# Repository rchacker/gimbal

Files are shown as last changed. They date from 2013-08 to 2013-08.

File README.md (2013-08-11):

gimbal
=======

Gimbal forked from _BruGi

Aim is to have a very simple 8 bit gimbal for which basic parameters are adjustable in the field without needing a computer.

Agouti Prototype

Agouti Prototype  
*Agouti Prototype*

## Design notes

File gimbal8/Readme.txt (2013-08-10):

Arduino -> Tools -> Serial Monitor Settings
  Baudrate: 11200 Baud, NL and CR

######################################
List of serial commands:
######################################

these are the preferred commands, use them for new GUIs !!

SD    (Set Defaults)
WE    (Writes active config to eeprom)
RE    (Restores values from eeprom to active config)
GC    (Recalibrates the Gyro Offsets)
par <parName> <parValue>   (general parameter read/set command)
    example usage:
       par                     ... list all config parameters
       par gyroPitchKi         ... list gyroPitchKi
       par gyroPitchKi 12000   ... set gyroPitchKi to 12000

HE     (print this output)
HE par (print config paramter description)	   

######################################
Config Parameters (list with "he par")
######################################

vers
  firmware version
  
versEEPROM
  eeprom version

gyroPitchKp/gyroRollKp
  pid controller P-value
gyroPitchKi/gyroRollKi
  pid controller I-value
gyroPitchKd/gyroRollKd
  pid controller D-value
accTimeConstant
  time constant of ACC complementary filter.
  controls how fast the gimbal follows ACC.
  unit = 1 sec, e.g. 7 = 7 seconds
mpuLPF
  low pass filter of gyro (DLPFMode)
  legal values are 0...6, 0=fastest 6=slowest
  use slow values if high frequency oscillations occur (still experimental)

angleOffsetPitch/angleOffsetRoll
  offset of gimbal zero position
  unit = 0.01 deg, e.g. 500 = 5.00 deg

dirMotorPitch/dirMotorRoll
  motor direction
  1 = normal, -1 = reverse direction
motorNumberPitch/motorNumberRoll
  assign motor output for pitch and roll, legal values are 0 or 1
maxPWMmotorPitch/maxPWMmotorRoll
  motor power, legal range 0 to 255

minRCPitch/minRCRoll
  RC minimum set point angle, unit = 1 deg
maxRCPitch/maxRCRoll
  RC maximum set point angle, unit = 1 deg
rcGain
  RC gain in Relative mode, specifies speed of gimbal movement
rcLPF
  RC low pass filter in Absolute mode, specified speed of gimbal movement
  unit = 0.1 sec, e.g. 20 = 2.0 seconds

rcModePPM
  0 ... use two RC PWM inputs on A0 and A1
  1 ... use PPM sum input on A0

rcChannelPitch
   RC channel assignment for RC pitch, legal values are 0 to 7 in PPM mode
rcChannelRoll
   RC channel assignment for RC roll, legal values are 0 to 7 in PPM mode

rcMid
   RC center position, unit = 1 msec, default=1500
rcAbsolute
   0 ... RC Relative Mode, gimbal position is incremented/decremented by RC
   1 ... RC Absolute Mode, RC controls gimbal directly

accOutput
   1 ... enable ACC printout for GUI chart display
enableGyro/enableACC
   1 ... enable Gyro/ACC update in control loop
         just for test and adjustment purposes

axisReverseZ
   0 ... sensor is mounted with component side up
   1 ... sensor is mounted with component side down
axisSwapXY
   0 ... standard X/Y sensor orientation
   1 ... swap X/Y, exchange roll/pitch function, when sensor is rotated 90 degrees

crc
   EEPROM checksum

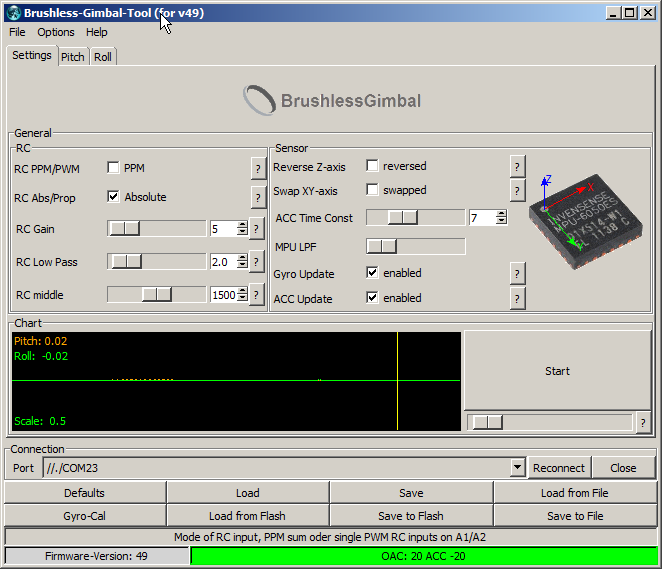
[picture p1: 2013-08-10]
GUI/Settings-GoPro-typical-Brugi_049_01.png

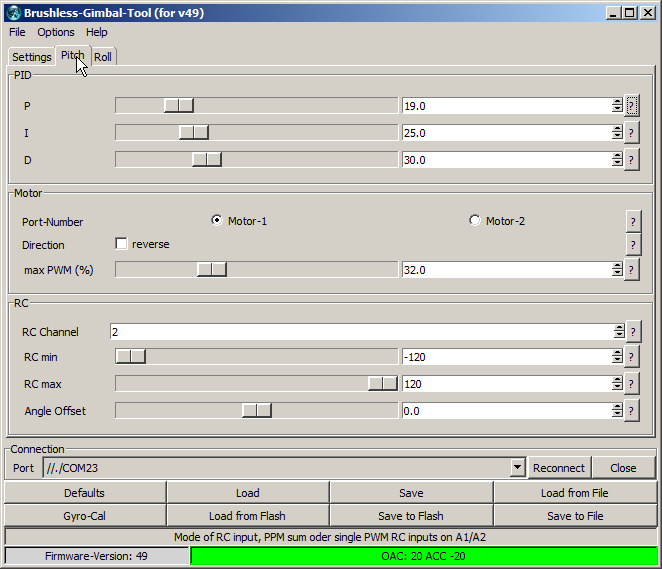
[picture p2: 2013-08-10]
GUI/Settings-GoPro-typical-Brugi_049_02.png

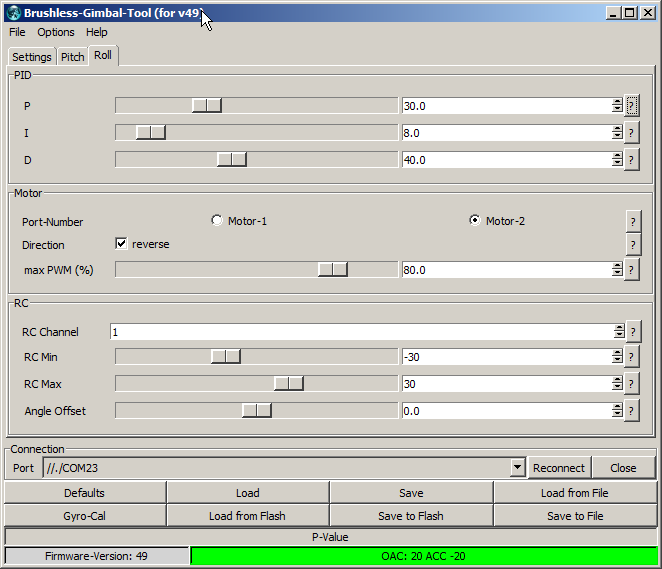
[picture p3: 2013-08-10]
GUI/Settings-GoPro-typical-Brugi_049_03.png

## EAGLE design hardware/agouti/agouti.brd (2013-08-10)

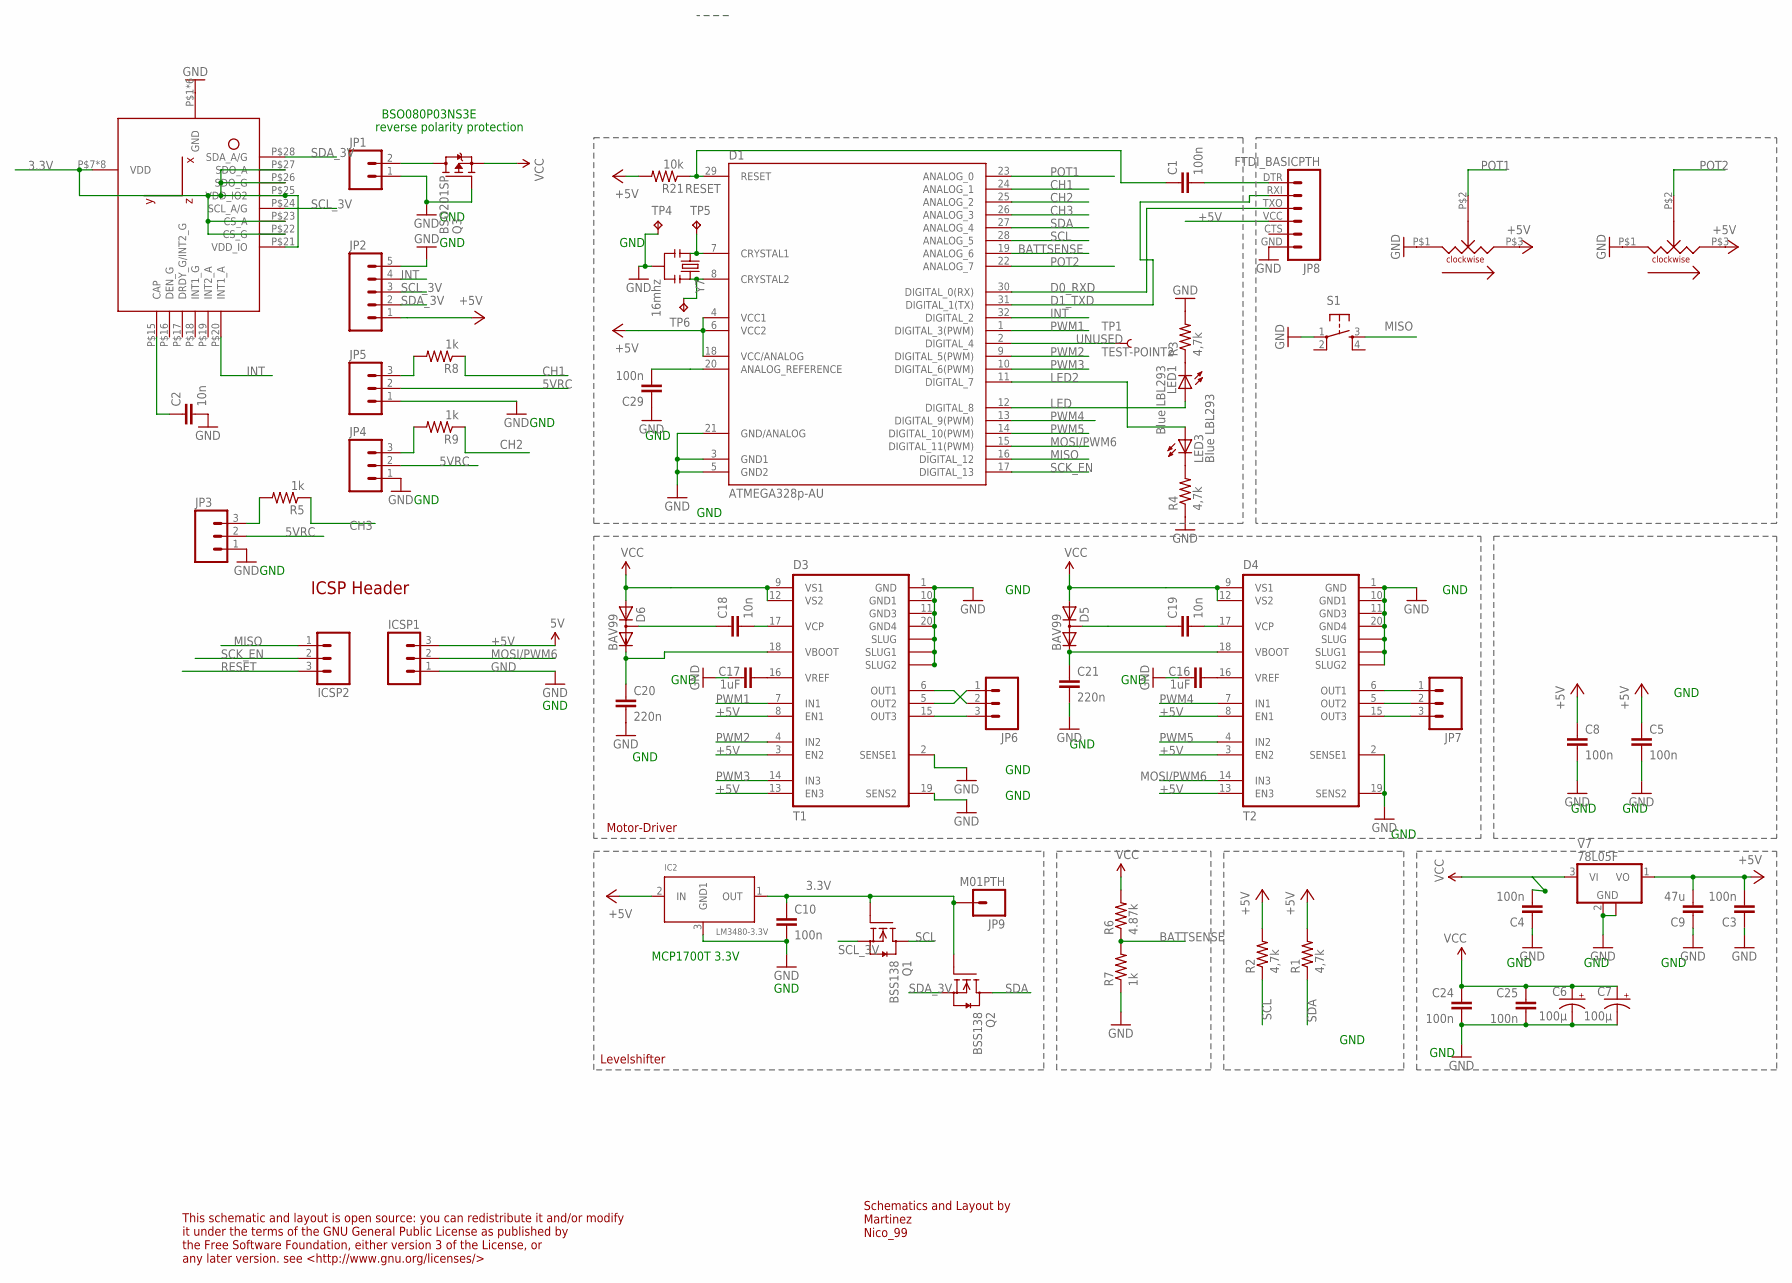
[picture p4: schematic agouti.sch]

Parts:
C1, C3, C4, C5, C8, C10, C24, C25, C29: 100n; 0805
C2, C18, C19: 10n; 0805
C6, C7: 100µ; PANASONIC_D
C9: 47u; C1210
C16, C17: 1uF; 0805
C20, C21: 220n; 0805
D1: ATMEGA328p-AU; TQFP32-08
D3: T1; SO20POWER2
D4: T2; SO20POWER2
D5, D6: BAV99; SOT23
IC2: LM3480-3.3V; SOT23
ICSP1, ICSP2: M03PTH; 1X03
JP1: M02PTH; 1X02
JP2: M05PTH; 1X05
JP3, JP4, JP5, JP6, JP7: M03PTH; 1X03
JP8: FTDI_BASICPTH; FTDI_BASIC
JP9: M01PTH; 1X01
LED1, LED3: Blue LBL293; CHIP-LED0603
Q1, Q2: BSS138; SOT23
Q3: BSO201SP; SO-8
R1, R2, R3, R4: 4,7k; 0805
R5, R7, R8, R9: 1k; 0805
R6: 4.87k; 0805
R21: 10k; 0805
S1: TAC_SWITCHSMD; TACTILE_SWITCH_SMD
TP1: TEST-POINT2; PAD.02X.02
TP4, TP5, TP6: TPTP06SQ; TP06SQ
U$3, U$5: TRIMMERPOT; BOURNES_3361P
U$6: LSM330; LGA-28
V7: 78L05F; SOT89
Y7: 16mhz; RESONATOR-SMD

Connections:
3.3V: C10.1, IC2.1 (OUT), JP9.1, Q1.1 (G), Q2.1 (G), U$6.P$7 (VDD), U$6.P$8 (VDD), U$6.P$9 (VDD), U$6.P$10 (VDD), U$6.P$11 (VDD), U$6.P$12 (VDD), U$6.P$13 (VDD), U$6.P$14 (VDD), U$6.P$21 (VDD_IO), U$6.P$22 (CS_G), U$6.P$23 (CS_A), U$6.P$25 (VDD_IO2), U$6.P$26 (SDO_G), U$6.P$27 (SDO_A)
5VRC: JP3.2, JP4.2, JP5.2
+5V: C3.2, C5.1, C8.1, C9.2, D1.4 (VCC1), D1.6 (VCC2), D1.18 (VCC/ANALOG), D3.3 (EN2), D3.8 (EN1), D3.13 (EN3), D4.3 (EN2), D4.8 (EN1), D4.13 (EN3), IC2.2 (IN), ICSP1.3, JP2.1, JP8.VCC (4), R1.2, R2.2, R21.2, U$3.P$3, U$5.P$3, V7.1 (VO)
BATTSENSE: D1.19 (ANALOG_6), R6.1, R7.2
CH1: D1.24 (ANALOG_1), R8.1
CH2: D1.25 (ANALOG_2), R9.1
CH3: D1.26 (ANALOG_3), R5.1
D0_RXD: D1.30 (DIGITAL_0(RX)), JP8.TXO (3)
D1_TXD: D1.31 (DIGITAL_1(TX)), JP8.RXI (2)
GND: C2.2, C3.1, C4.1, C5.2, C6.-, C7.-, C8.2, C9.1, C10.2, C16.1, C17.1, C20.2, C21.2, C24.2, C25.2, C29.1, D1.3 (GND1), D1.5 (GND2), D1.21 (GND/ANALOG), D3.1 (GND), D3.2 (SENSE1), D3.10 (GND1), D3.11 (GND3), D3.19 (SENS2), D3.20 (GND4), D3.SLUG (SLUG1), D3.SLUG1 (SLUG2), D3.SLUG2 (SLUG), D4.1 (GND), D4.2 (SENSE1), D4.10 (GND1), D4.11 (GND3), D4.19 (SENS2), D4.20 (GND4), D4.SLUG (SLUG1), D4.SLUG1 (SLUG2), D4.SLUG2 (SLUG), IC2.3 (GND1), ICSP1.1, JP1.1, JP2.5, JP3.1, JP4.1, JP5.1, JP8.GND (6), Q3.4 (G), R3.2, R4.1, R7.1, S1.1, TP4.TP, U$3.P$1, U$5.P$1, U$6.P$1 (GND), U$6.P$2 (GND), U$6.P$3 (GND), U$6.P$4 (GND), U$6.P$5 (GND), U$6.P$6 (GND), V7.2 (GND), V7.2@1 (GND), Y7.2
INT: D1.32 (DIGITAL_2), JP2.4, U$6.P$20 (INT1_A)
LED: D1.12 (DIGITAL_8), LED1.A
LED2: D1.11 (DIGITAL_7), LED3.A
MISO: D1.16 (DIGITAL_12), ICSP2.1, S1.3
MOSI/PWM6: D1.15 (DIGITAL_11(PWM)), D4.14 (IN3), ICSP1.2
unnamed: LED1.C, R3.1
unnamed: LED3.C, R4.2
unnamed: JP1.2, Q3.5 (D), Q3.6 (D), Q3.7 (D), Q3.8 (D)
unnamed: JP3.3, R5.2
unnamed: JP5.3, R8.2
unnamed: JP4.3, R9.2
unnamed: C16.2, D4.16 (VREF)
unnamed: C17.2, D3.16 (VREF)
unnamed: C1.2, JP8.DTR (1)
unnamed: C2.1, U$6.P$15 (CAP)
unnamed: C18.2, D3.17 (VCP)
unnamed: C19.2, D4.17 (VCP)
unnamed: C19.1, D5.3 (AC)
unnamed: C21.1, D4.18 (VBOOT), D5.2 (C)
unnamed: D3.15 (OUT3), JP6.3
unnamed: D4.6 (OUT1), JP7.1
unnamed: D4.5 (OUT2), JP7.2
unnamed: D4.15 (OUT3), JP7.3
unnamed: D3.5 (OUT2), JP6.1
unnamed: D3.6 (OUT1), JP6.2
unnamed: D1.8 (CRYSTAL2), TP6.TP, Y7.3
unnamed: D1.7 (CRYSTAL1), TP5.TP, Y7.1
unnamed: C29.2, D1.20 (ANALOG_REFERENCE)
POT1: D1.23 (ANALOG_0), U$3.P$2
POT2: D1.22 (ANALOG_7), U$5.P$2
PWM1: D1.1 (DIGITAL_3(PWM)), D3.7 (IN1)
PWM2: D1.9 (DIGITAL_5(PWM)), D3.4 (IN2)
PWM3: D1.10 (DIGITAL_6(PWM)), D3.14 (IN3)
PWM4: D1.13 (DIGITAL_9(PWM)), D4.7 (IN1)
PWM5: D1.14 (DIGITAL_10(PWM)), D4.4 (IN2)
RESET: C1.1, D1.29 (RESET), ICSP2.3, R21.1
SCK_EN: D1.17 (DIGITAL_13), ICSP2.2
SCL: D1.28 (ANALOG_5), Q1.3 (D), R2.1
SCL_3V: JP2.3, Q1.2 (S), U$6.P$24 (SCL_A/G)
SDA: D1.27 (ANALOG_4), Q2.3 (D), R1.1
SDA_3V: JP2.2, Q2.2 (S), U$6.P$28 (SDA_A/G)
UNUSED: D1.2 (DIGITAL_4), TP1.P$1
VBOOT1: C20.1, D3.18 (VBOOT), D6.2 (C)
VCC: C4.2, C6.+, C7.+, C24.1, C25.1, D3.9 (VS1), D3.12 (VS2), D4.9 (VS1), D4.12 (VS2), D5.1 (A), D6.1 (A), Q3.1 (S), Q3.2 (S), Q3.3 (S), R6.2, V7.3 (VI)
VCP1: C18.1, D6.3 (AC)

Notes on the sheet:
MCP1700T 3.3V
Motor-Driver
Levelshifter
This schematic and layout is open source: you can redistribute it and/or modify it under the terms of the GNU General Public License as published by the Free Software Foundation, either version 3 of the License, or any later version. see <http://www.gnu.org/licenses/>
Schematics and Layout by Martinez Nico_99
ICSP Header
GND
BSO080P03NS3E
reverse polarity protection

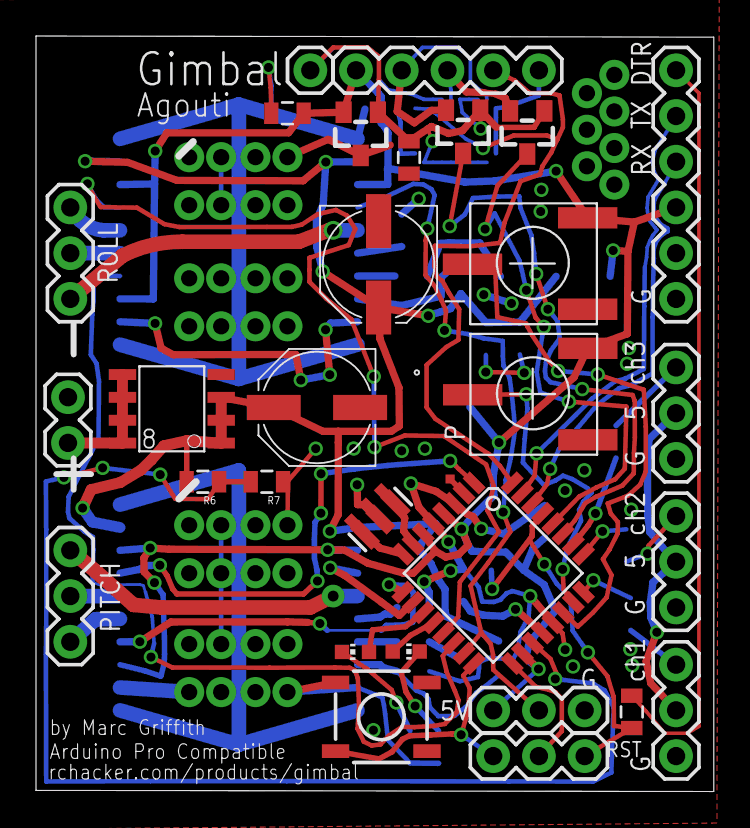
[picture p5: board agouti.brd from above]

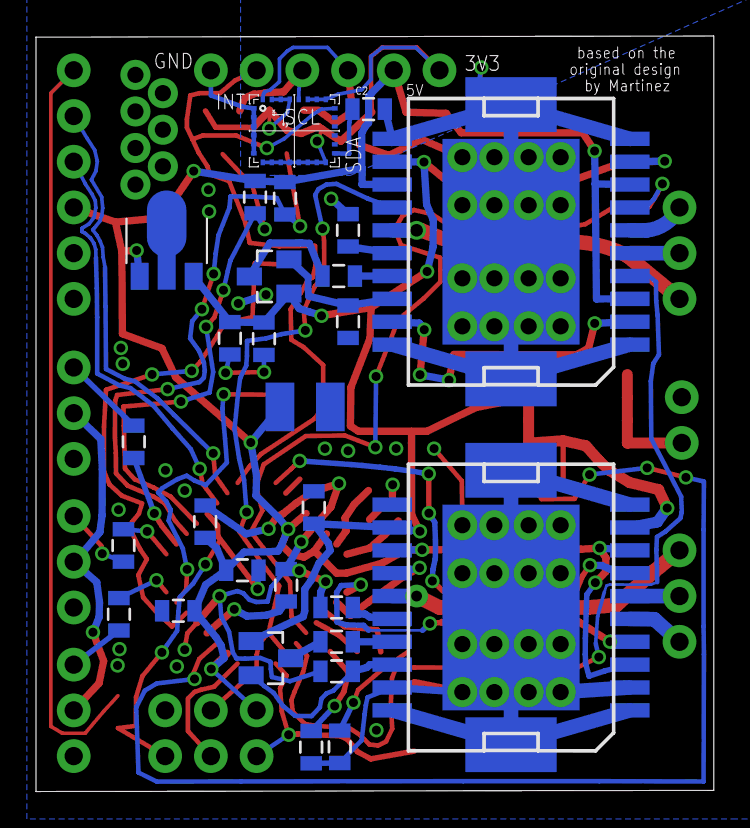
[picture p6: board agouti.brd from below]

Board: 2 copper layers, 37.7 x 42.0 mm, 62 parts (28 on the bottom side), 55 nets.

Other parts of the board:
U$2: RCHACKERLOGOBMP

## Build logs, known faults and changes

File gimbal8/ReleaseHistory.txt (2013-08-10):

23.6.2013
Version 049 r156
* new config versEEPROM, eeprom is initialized when versEEPROM changes
* added CRC checks to EEPROM structure

22.6.2013
Version 049 r155
RCmin and RCmax are not constrained any more, they can be set independent from each other.
 * in Absolute Mode: RC direction can be changed by sign change of RCmin/RCmax
 * in Relative Mode: RC direction can be changed by choosing RCgain negative. RCmin/RCmax act as angle limits
 
20.6.2013
Version 049 r153
fixed acc initialization issues
accMag calculation used uninitialized value

15.6.2013
Version 049 r152
minor bug fixes
  * accOutput=false when saved to EEPROM_readAnything
  * PID I default value updated

12.6.2013
Version 049 r77
* code size reduction, because some non UNO platforms have flash size issues
  * reworked RC handling and bug fixes (thanks to micha-24 for the contribution)
  * RC channels numbers match AOI naming now
  * GUI help text enhancements
  * reduced control noise, changed PID I scale (by 10)

*******************************
  Important Note for r77
*******************************
  ->  PID I must be divided by 10 for same result
      e.g. instead I=60 use I=6

General Note:
  If you update from earlier versions, EEPROM parameters should be reset to their initial values.
Use console command SD and WE
or in blg_tools GUI "defaults" and "save to flash" 

7.6.2013
049B r69
  * GUI updates by meister
  * minor bug fixes
  * updated release history and readme.txt
	  
3.6.2013	  
049 r61:
- minor bug fix: "par" command did not accept all names 

2.6.2013
049 r58:
IMPORTANT: a known issue exist in "par" command handling (it does not accept all parameter names)
use 049 r61 instead

* RC improvements
  - support of PPM sum signal
  - rc channel numbers can be assigned to functions separately
  - config for RC low pass filter
  - config for mpu lpf
  - config for gimbal zero positions
* improved gyro calibration, should be more reliable now
* p-value 16-bit overrun fixed
* unified config parameter setting with new "par" command
* minor fixes

28.5.2013
049 r45:
- RC +/-45 degree glitch fixed at pitch, roll still unchanged
- faster lock at startup
- OAC output runs at 25Hz, is same rate as used by 046...
- RC low pass filters have been set slower in absolute mode

23.5.2013
049 r40:
- RC functionality has been refined, runs smoothly now
- gyro calibration improved, still calibration is unprecise occasionally

20.5.2013
049 ALPHA r34:
- major rework, with new IMU calculation and PID controller.
  (the actual numbers for P,I and D have no relation to previous versions, see example screenshots in GUI dir for reference)
- proper handling of camera facing down (pitch 90 deg).
- sensor orientation can be configured (see new command SSO).

open issues are
- RC mode movements not smooth enough.
- RC relative mode not functional.
- GUI needs upgrade by meister :-)

048 B: quite some work
- Refactoring of code to increase maintainability
- Auto detect of MPU address (thanks to meister)
- complete rework of controller algorithm (Alois Hahn, Thanks!)
  P is Proportional gain for Gyro
  D is Damping gain for Gyro
  I is integral gain for ACC Drift compensation and horizon stabilization
  
  Should be way easier to find correct parameters now
  But beware: The numbers for P,D and I have nothing to do with numbers from previous versions

- Gravity weighted Drift compensation
- Reduced floating point operations, main control loop runs now at 1kHz (was 450 to 700Hz)
- new gyro calibration: routine detects movements and starts over as long as the gimbal is not free of movement.
- Switching routine for gyro axes to allow for 90deg view downwards without the gimbal going ape
- reworked RC Control algortihm
- modified and included meisters GUI (again: thanks to Alois Hahn)

To be done: Cleanup of Serial Protocol, Cleanup of TCL GUI, still some issues when looking downward....

047 B:
- internal development Version, not released

046 B: minor bugfixes (actually bugfixes that should have been in 045B)and improvements
- introduce rcGain parameter to influence movement rate over rc controll
- modified and included meisters GUI

045 B: minor bugfixes and improvements, switched to Beta status
- change PID parameters to long int, resolution is still 0.001 (to overcome the 32 limit)
- change resolution for ACC weight to 0.0001 (for better fine tuning)
- modified and included meisters GUI

044 A: 
- add choice between absolute and proportional RC positioning
- add continious angle output for debugging/GUI purposes, toggled by serial command
- add choice between raw ACC and DMP for Horizont stabilization
  (DMP is experimental for now, PIDs have to be changed/lowered)
  (Default is ACC)
- Serial Protocol:
WE    (Writes active config to eeprom)
RE    (Restores values from eeprom to active config)
TC    (transmits all config values in eeprom save order)
SD    (Set Defaults)
SP gyroPitchKp gyroPitchKi gyroPitchKd    (Set PID for Pitch)
SR gyroRollKp gyroRollKi gyroRollKd    (Set PID for Roll)
SA accelWeight    (Set Weight in accelWeight/1000)
SF nPolesMotorPitch nPolesMotorRoll
SE maxPWMmotorPitch maxPWMmotorRoll     (Used for Power limitiation on each motor 255=high, 1=low)
SM dirMotorPitch dirMotorRoll motorNumberPitch motorNumberRoll
GC    (Recalibrates the Gyro Offsets)
TRC   (transmitts RC Config)
SRC minRCPitch maxRCPitch minRCRoll maxRCRoll (angles -90..90)
SCA rcAbsolute (1 = true, RC control is absolute; 0 = false, RC control is proportional)
TCA   (Transmit RC control absolute or not)
UAC useACC (1 = true, ACC; 0 = false, DMP)
TAC   (Transmit ACC status)
OAC accOutput (Toggle Angle output in ACC mode: 1 = true, 0 = false)
ODM dmpOutput  (Toggle Angle output in DMP mode: 1 = true, 0 = false)
HE    (This output)

043 A: 
- introduce RC Channel input :-)
  Use A1 and A2 as PWM input pins for Pitch and Roll, DO NOT CONNECT +5V from REC-Receiver to Controller
- add RC input config to serial protocol  
  Type HE in terminal to see additional Protocol stuff (min max Angles per Axis)
- start Code optimization: atan2 now runs ~2 times faster

042 A: 
- memory optimizations
- reintroduce a way to motor power control (use fixed progmem arrays):
PWM from 1 to 255

041 A: MAJOR UPDATE!!!
- removed "config.h", added serial protocol
-- configurable parameters now stored in eeprom
-- relevant parameters can be changes online now
- Still: floating point math!!!
-CAVEAT only 100%Power for now, was not able to finish that this weekend.

040 A: Test version, not published

039 A: MAJOR REWORK!!!
- Removed usage of DMP completely
- Relay on raw Gyro and raw ACC only! 
Gyro is used at ~1kHz to counter movements, ACC vs set point
is mixed into gyro signal to ensure horizontal camera (IMU) position
- global max PWM duty cycle and Power devider per motor can be configured in config.h 
Hint: lower torque = lower power allows for higher P on Pitch for me.
- code cleanup, removed obsolete stuff.
- 32kHz PWM works now for motor movement updates for up to 8 kHz. 
( No more beeping :-), i dont care for energy loss at the moment )

038 A: Test version, not published

037 A:
- NEW: Motor Power Management. Two Options: 
  -- Fixed max Torque/Power (caveat: 
  -- Lower Torque/Power for slower Movements -> EXPERIMENTAL (removed in 039)
- NEW: Use DMP output for I and D Part in control loop at 100Hz (or 200Hz), use raw Gyro at 500Hz for P-Part 
  -- Caveat: setting the sample rate to 500Hz for gyro screws up the dmp algorithm for now. 
     Some more research required ro configure the mpu correctly.
     Therefore sample rate for gyro is set to 200Hz as well, resulting in loss of accuracy.
  --> Remove choice of DMP/RAW_GYRO
- Code cleanup
- Removed the wiring.c modificitaions, does not work as intented anyway --> back to CC_FACTOR usage
- Moved some definitions from config.h to definitions.h, dont change them for now.
- Switched off Gyro and Accel write to DMP-FIFO, speeding up the code by ~200us per DMP read

036 A:
- Choose between DMP and Raw Gyro Stabilisation
  (Raw Gyro is only a tech demo implementation for now: P controller only, no setpoint)
- Faster Motor routine using uint8_t overflow for counter. Sinus Array length therefore is fixed now to 256.
- Raw Gyro can be filtered with low pass (change alpha below)
- YOU HAVE TO CHANGE wiring.c, see below !!!!
- DOES IT WORK? Well....no fo now.
*/

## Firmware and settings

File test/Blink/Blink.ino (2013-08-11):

/*
  Blink
  Turns on an LED on for one second, then off for one second, repeatedly.
 
  This example code is in the public domain.
 */
 
// Pin 13 has an LED connected on most Arduino boards.
// give it a name:
int green = 7;
int red = 8;

// the setup routine runs once when you press reset:
void setup() {                
  // initialize the digital pin as an output.
  pinMode(green, OUTPUT);
  pinMode(red, OUTPUT);  
}

// the loop routine runs over and over again forever:
void loop() {
  digitalWrite(green, HIGH);   
  digitalWrite(red, LOW);
  delay(500);               
  digitalWrite(green, LOW);
  digitalWrite(red, HIGH);
  delay(500);             
}

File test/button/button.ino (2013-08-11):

int pushButton = 12;
int green = 7;
int red = 8;

void setup() {
  
  pinMode(pushButton, INPUT);
  digitalWrite(pushButton, HIGH);
  
  pinMode(green, OUTPUT);
  pinMode(red, OUTPUT); 
  
  
}

void loop() {
  
  if( digitalRead(pushButton))
  {
   digitalWrite(green, HIGH);
  digitalWrite(red, LOW); 
    
  }
  else
  {
    digitalWrite(green, LOW); 
  digitalWrite(red, HIGH);
  
    
    
  }
 
}

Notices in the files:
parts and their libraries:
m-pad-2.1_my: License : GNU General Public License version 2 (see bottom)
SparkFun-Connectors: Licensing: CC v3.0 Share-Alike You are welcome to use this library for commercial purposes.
